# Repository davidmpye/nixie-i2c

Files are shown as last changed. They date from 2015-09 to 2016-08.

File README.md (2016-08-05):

# nixie-i2c

Nixie-I2C is a collection of PCB designs and accompanying library designed to simplify using [Nixie tubes](http://en.wikipedia.org/wiki/Nixie_tube) with Arduino and ESP8266 based boards (and perhaps others in future).

## Design

Driving nixie tubes from microcontrollers can present several issues:
 - Can rely on expensive/obsolute/irreplacable Soviet-era driver ICs (eg K155ID1)
 - Or, if you drive the cathodes directly, requires a large number of pins from the microcontroller (e.g a numeric IN-14 nixie tube has 12 cathodes - 0-9 and left/right decimal places), so it becomes difficult to direct-drive multiple tubes without running out of IO pins
 - If using the 'direct drive' solution above, you need a high-voltage capable transistor per cathode.
 
The main idea of this project is to provide a convenient driver board for a nixie tube, allowing it to be controlled from the microcontroller via I2C.

## Features

The PCB design here (which is tested and works) offers the following features:
 - Bus based (I2C) - put all your tubes in a row on stripboard or similar!
 - Designed for IN-14 nixie tube
 - I2C address (3-bit) settable (solder-pads on underside of board), allowing 9 nixie tubes per I2C bus.
 - Handles all HV switching, allowing a simple library interface to select the digit to be displayed.  Uses cheap SMD NPN transistors (MMBTA42s)
 - Has option for installing a programmable RGB (WS2812B) LED under the base of each tube, allowing bottom-lighting of any colour/brightness, without requiring ongoing control from the microcontroller (eg no PWM timing loops etc)
 - Eagle brd/sch files provided
 - Licenced under the OSHW framework
 
 There is an accompanying library, which supports:
 - Arduino or ESP8266
 - Simple interface to setting a tube's display digit / decimal point status
 - Slot-machine display for cathode protection
 - Direct drive for up to 9 tubes (per I2C bus), no multiplexing/timer loops from the microntroller required
 
##Example

 The library is designed to be simple and easy to use:
 ```
 Nixie_i2c nix0(0x00);
 nix0.slotMachineDisplayNumber(1);  //Tube now displays 1
 delay(1000);
 nix0.slotMachineDisplayNumber(9);  //Tube now displays 9
 ```

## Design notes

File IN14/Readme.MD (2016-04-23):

#IN-14 Nixie Tube I2C PCB design

##Tech Specs:
- Overall dimensions: 24mm x  52.5mm
- Nixie tube centre point: 12mm (ie in the middle of the board in X), 12.3mm in from front edge
- Screw fixing centre 1: 3.25 from edge, 3.25 in from front of board
- Screw fixing centre 2: 3mm from other edge, 19.75mm in from front of board
- Screw hole size: M3
- Pinout(from front to rear):
- - +HV (~170VDC)
- - GND (Common between +HV and VCC)
- - LED_DATA_IN (signal 'in' to WS2812B)
- - LED_DATA_OUT (signal 'out' to next WS2812B in chain)
- - VCC (3.3-5VDC)
- - SCL  (single external 4k7 pull-UP resistor per bus advisable)
- - SDA  (single external 4k7 pull-UP resistor per bus advisable)

##Parts list:
###Top side of board:
- 1x IN-12 nixie tube
- 1x Nixie tube base (3d printable one available as STL file in this folder, with cutout for WS2812B LED)
- 1x WS2812B LED (optional but good!)
- 1x MCP23017 I2C multiplexer IC (SMD)
- 1x 0806 anode resistor 
- 3x 0604 4k7 SMD resistor arrays

##Hints

- Solder the resistor arrays in to place first (flood soldering works best)
- Solder the I2C multiplexer chips and other parts in to place
- Set the I2C address bits on the rear side of the board - bridging the middle and left pad sets the bit to 0, middle and right sets the bit to 1.  Bridging all three pins shorts VCC to GND!
- If mounting PCB to the case, it's best to use nylon bolts - reducing the risk of an electrical fault allowing the anode voltage appearing on the outside of a case!

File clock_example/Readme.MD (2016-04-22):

# Example Arduino/ESP8266 sketch

This is an example sketch for a 6-tube Nixie Clock.

The clock is designed around the IN-14 Nixie-I2C project.

##Parts needed:

-Microcontroller (ESP8266/Arduino etc)
-I2C RTC (Cheap battery-backed DS3232)
-HV PSU (I used one from [PV Electronics](http://www.pvelectronics.co.uk/) but anything suitable for driving the tubes will work.
-6 tubes and i2c boards
-I used a transistor pair to make it possible to PWM dim the HV supply to the tubes, meaning the tube brightness can be dimmed for night-time use.

The clock displays HH MM SS, and the bottom-light colour for the tubes changes throughout the day (from green in the early morning through blues in the afternoon to red by night time)

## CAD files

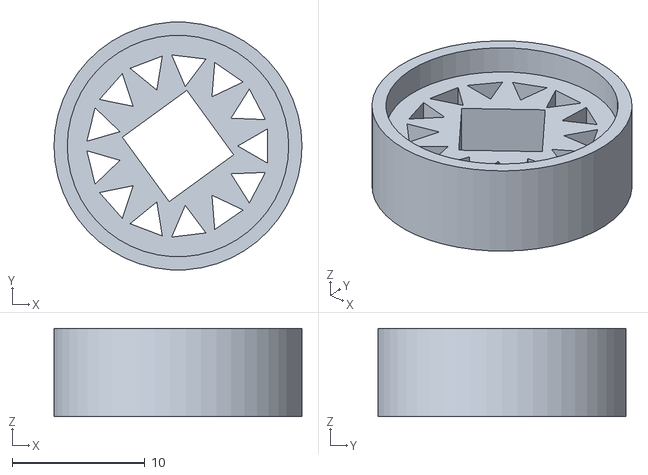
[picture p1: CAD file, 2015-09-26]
IN14/IN14_base.stl
18.7 x 18.6 x 6.65

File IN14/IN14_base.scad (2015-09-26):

outer_dia =  18.67;
lip_height = 2;
lip_width = 1;
total_height = 6.65;

led_length = 6;
led_width = 6;

difference() {

cylinder(r=outer_dia/2, h=total_height, $fn=50);
translate([0, 0, total_height - lip_height]) cylinder(r=(outer_dia/2) - lip_width, h=lip_height + 1, $fn=50);

rotate(360/10,[0,0,1]) translate([-led_length/2,-led_width/2, -1]) cube([led_length, led_width, total_height + 2]);


for (i = [0 : 12]) {

rotate(i * (360/13),[0,0,1]) translate([6,0,-1]) polyhole(total_height + 2, 1.5);
 }
}


module polyhole(h, d) {
    n = max(round(2 * d),3);
    rotate([0,0,180])
        cylinder(h = h, r = (d / 2) / cos (180 / n), $fn = n);
}

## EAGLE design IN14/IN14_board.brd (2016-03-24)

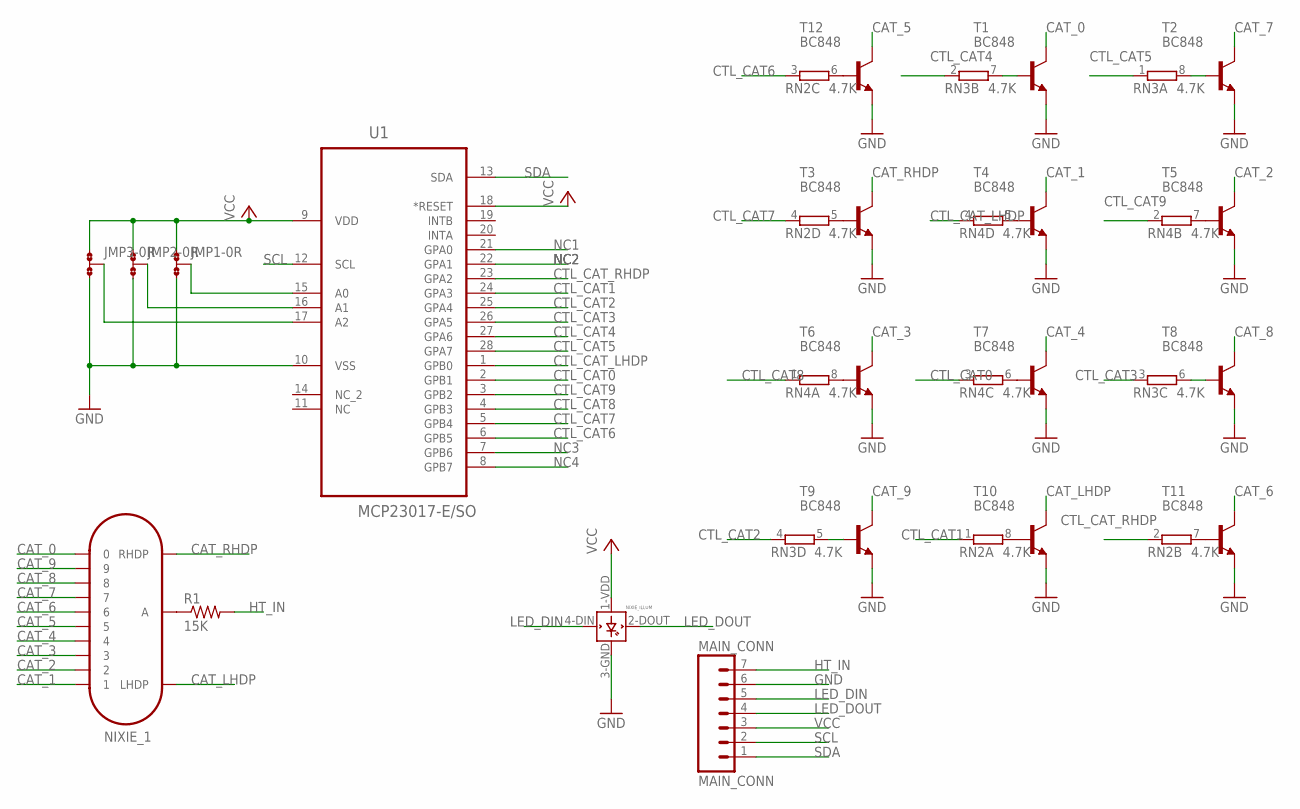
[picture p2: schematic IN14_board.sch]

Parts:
JMP1, JMP2, JMP3: 0R-JUMPA; A0R-JMP
MAIN_CONN: MAIN_CONN; 1X07_LONGPADS
NIXIE_1: IN-14
NIXIE_ILLUM: WS2812B
R1: 15K; 0603-RES
RN2, RN3, RN4: 4.7K; EXB38V
T1, T2, T3, T4, T5, T6, T7, T8, T9, T10, T11, T12: BC848; SOT23
U1: MCP23017-E/SO; SOIC127P1032X265-28N

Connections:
CAT_0: NIXIE_1.0, T1.3 (C)
CAT_1: NIXIE_1.1, T4.3 (C)
CAT_2: NIXIE_1.2, T5.3 (C)
CAT_3: NIXIE_1.3, T6.3 (C)
CAT_4: NIXIE_1.4, T7.3 (C)
CAT_5: NIXIE_1.5, T12.3 (C)
CAT_6: NIXIE_1.6, T11.3 (C)
CAT_7: NIXIE_1.7, T2.3 (C)
CAT_8: NIXIE_1.8, T8.3 (C)
CAT_9: NIXIE_1.9, T9.3 (C)
CAT_LHDP: NIXIE_1.LHDP, T10.3 (C)
CAT_RHDP: NIXIE_1.RHDP, T3.3 (C)
CTL_CAT0: RN4.3 (1), U1.2 (GPB1)
CTL_CAT1: RN2.1, U1.24 (GPA3)
CTL_CAT2: RN3.4 (1), U1.25 (GPA4)
CTL_CAT3: RN3.3 (1), U1.26 (GPA5)
CTL_CAT4: RN3.2 (1), U1.27 (GPA6)
CTL_CAT5: RN3.1, U1.28 (GPA7)
CTL_CAT6: RN2.3 (1), U1.6 (GPB5)
CTL_CAT7: RN2.4 (1), U1.5 (GPB4)
CTL_CAT8: RN4.1, U1.4 (GPB3)
CTL_CAT9: RN4.2 (1), U1.3 (GPB2)
CTL_CAT_LHDP: RN4.4 (1), U1.1 (GPB0)
CTL_CAT_RHDP: RN2.2 (1), U1.23 (GPA2)
GND: JMP1.3, JMP2.3, JMP3.3, MAIN_CONN.6, NIXIE_ILLUM.3-GND (GND), T1.2 (E), T2.2 (E), T3.2 (E), T4.2 (E), T5.2 (E), T6.2 (E), T7.2 (E), T8.2 (E), T9.2 (E), T10.2 (E), T11.2 (E), T12.2 (E), U1.10 (VSS)
HT_IN: MAIN_CONN.7, R1.2
LED_DIN: MAIN_CONN.5, NIXIE_ILLUM.4-DIN (DIN)
LED_DOUT: MAIN_CONN.4, NIXIE_ILLUM.2-DOUT (DOUT)
unnamed: RN3.8 (2), T2.1 (B)
unnamed: JMP1.2, U1.15 (A0)
unnamed: RN3.7 (2), T1.1 (B)
unnamed: NIXIE_1.A, R1.1
unnamed: RN3.6 (2), T8.1 (B)
unnamed: JMP2.2, U1.16 (A1)
unnamed: RN2.5 (2), T3.1 (B)
unnamed: JMP3.2, U1.17 (A2)
unnamed: RN4.5 (2), T4.1 (B)
unnamed: RN4.8 (2), T6.1 (B)
unnamed: RN3.5 (2), T9.1 (B)
unnamed: RN4.7 (2), T5.1 (B)
unnamed: RN4.6 (2), T7.1 (B)
unnamed: RN2.6 (2), T12.1 (B)
unnamed: RN2.7 (2), T11.1 (B)
unnamed: RN2.8 (2), T10.1 (B)
NC1: U1.21 (GPA0)
NC2: U1.22 (GPA1)
NC3: U1.7 (GPB6)
NC4: U1.8 (GPB7)
SCL: MAIN_CONN.2, U1.12 (SCL)
SDA: MAIN_CONN.1, U1.13 (SDA)
VCC: JMP1.1, JMP2.1, JMP3.1, MAIN_CONN.3, NIXIE_ILLUM.1-VDD (VDD), U1.9 (VDD), U1.18 (*RESET)

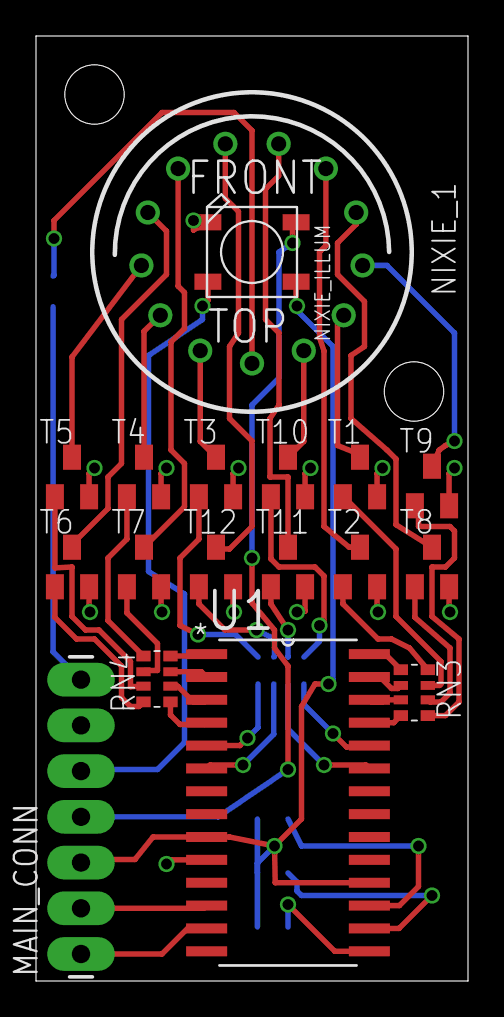
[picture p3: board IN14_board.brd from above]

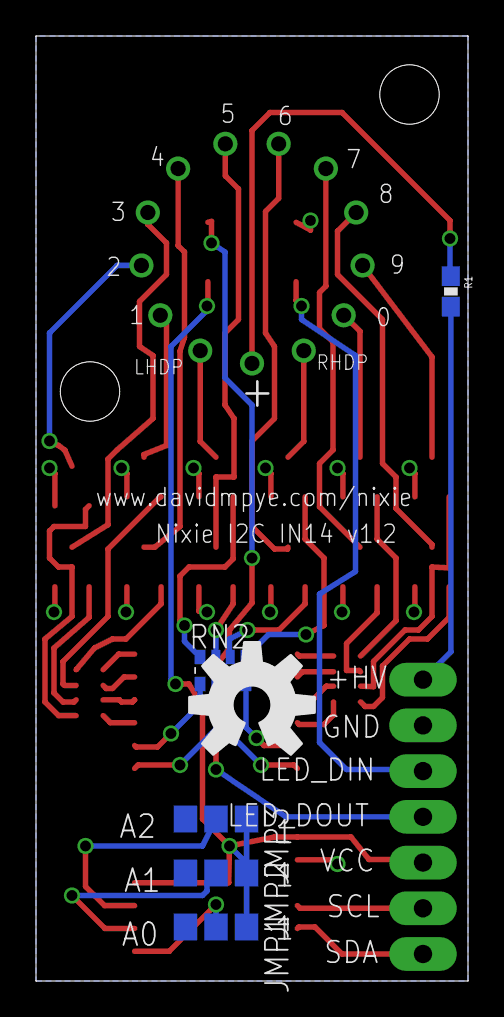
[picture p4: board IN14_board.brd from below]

Board: 2 copper layers, 24.0 x 52.5 mm, 26 parts (6 on the bottom side), 47 nets.

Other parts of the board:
U$1: OSHW-LOGO-L
U$2, U$5: STAND-OFF

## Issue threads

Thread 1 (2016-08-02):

Which transistors are used to drive the cathodes?

msurguy, 2016-08-02:
Hi!

It looks like that the requirements are not listing transistors used in the schematics, could you add them to the readme please?

davidmpye, 2016-08-05:
Oops - they are MMBTA42s.

(e.g. http://uk.farnell.com/webapp/wcs/stores/servlet/ProductDisplay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)

I'll update readme.

Regards

David

msurguy, 2016-08-05:
👍 thanks!

davidmpye, 2016-08-05:
I'm working on a new version of nixie-i2c, which will actually use shift registers, and the boards will be chainable directly (so it'll be nixie-shift, or something ;-)

msurguy, 2016-08-05:
@davidmpye That's great to hear!

I will follow this project but meanwhile I will use Raspberry Pi Zero and Arduinix to control 6 nixie tubes. Really interested in cost efficient addressable single tube solution though, keep up the great work!

msurguy, 2016-08-05:
PS @davidmpye if you haven't already, I highly suggest you put this project on Hackaday.io and let people like me easily follow your progress :)

Closed 2016-08-05.

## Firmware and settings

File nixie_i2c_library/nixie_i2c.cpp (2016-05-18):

/*
  nixie_i2c.cpp - Library for David Pye's nixie i2c boards.
  Created by Dr David Pye - Sept 2015
  Licenced under the GNU GPL v3
*/
#include <nixie_i2c.h>

#define RHDP_PIN 12 
#define LHDP_PIN 3

int Nixie_i2c::_pins[10] = { 8, 6, 4, 5, 7, 2, 13, 9, 11, 10 };

Nixie_i2c::Nixie_i2c(uint8_t i2c_address) {
  _i2c_address = i2c_address;
  
  _currentNumber = -1;
  _lhdpState = _rhdpState = false;
}

void Nixie_i2c::init() {
  _mcp.begin(_i2c_address);
  //Set all pins to o/p
  for (int i=0; i<16; ++i) _mcp.pinMode(i, OUTPUT);
  blank();
}

void Nixie_i2c::displayNumber(int number) {
  _currentNumber = number;
  unblank();
}

void Nixie_i2c::slotMachineDisplayNumber(int newNumber) {

  bool orig_lhdp = _lhdpState;
  bool orig_rhdp = _rhdpState;

  int num = _currentNumber;
  for (int numPasses = 10 + newNumber - num; numPasses >0; --numPasses)  {
 	if (num == 9) num = 0; else num++;

 	//toggle the lhdp/rhdp cathodes as we go round.
 	_lhdpState = !_lhdpState;
    	_rhdpState = !_rhdpState;
	if (numPasses == 1) {
		//Put the decimal point statuses back to the correct ones!
		_lhdpState = orig_lhdp;
		_rhdpState = orig_rhdp;
	}
	displayNumber(num);
	delay(50);
  }
}

void Nixie_i2c::blank() {
  //Set all outputs low
  _mcp.writeGPIOAB(0x0000);
}

void Nixie_i2c::unblank() {
  uint16_t b = 0x0000;
  if (_rhdpState) b |= 1<<RHDP_PIN;
  if (_lhdpState) b |= 1<<LHDP_PIN;
  b |= 1 << _pins[_currentNumber];
  _mcp.writeGPIOAB(b);
}

int Nixie_i2c::currentNumber() {
  return _currentNumber;
}

void Nixie_i2c::setRhdp(bool state) {
  _rhdpState = state;
  _mcp.digitalWrite(RHDP_PIN, _rhdpState ? HIGH: LOW);
}

void Nixie_i2c::setLhdp(bool state) {
  _lhdpState = state;
  _mcp.digitalWrite(LHDP_PIN, _lhdpState ? HIGH: LOW);
}
    

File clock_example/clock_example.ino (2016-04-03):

#include <nixie_i2c.h>
#include <Adafruit_MCP23017.h>
#include <Wire.h>
#include <Adafruit_NeoPixel.h>
#include <DS3232RTC.h>    //http://github.com/JChristensen/DS3232RTC
#include <Time.h>

#define ANODE_PWM_PIN 13

Nixie_i2c nix0(0);
Nixie_i2c nix1(1);

Nixie_i2c nix2(2);
Nixie_i2c nix3(3);
Nixie_i2c nix4(4);
Nixie_i2c nix5(5);

//   #define SET_TIME

//Descriptor for the WS2812 LEDs in the nixie boards
Adafruit_NeoPixel strip = Adafruit_NeoPixel(6, 12, NEO_GRB + NEO_KHZ800);

void setup() {
  Wire.begin(5, 4);

  nix0.init();
  nix1.init();
  nix2.init();
  nix3.init();
  nix4.init();
  nix5.init();

  //set the tubes to full brightness
  pinMode(ANODE_PWM_PIN, OUTPUT);
  analogWrite(ANODE_PWM_PIN, 1024);

  strip.begin();
  strip.setBrightness(100);
  strip.show();

  //Get the current time from the RTC
  setSyncProvider(RTC.get);

#ifdef SET_TIME
  tmElements_t tm;
  tm.Hour = 16;             //set the tm structure to 23h31m30s on 13Feb2009
  tm.Minute = 43;
  tm.Second = 0;
  tm.Day = 03;
  tm.Month = 04;
  tm.Year = 2016 - 1970;    //tmElements_t.Year is the offset from 1970
  RTC.write(tm);
  
#endif

  setColons(true);

}

int lastMinute = -1; //used for RGB colour updates

void loop() {
  time_t currentTime = now();
  int scratch;
  scratch = hour(currentTime) / 10;
  if (nix5.currentNumber() != scratch)  nix5.slotMachineDisplayNumber(scratch);
  scratch = hour(currentTime) % 10;
  if (nix4.currentNumber() != scratch) nix4.slotMachineDisplayNumber(scratch);

  scratch = minute(currentTime) / 10;
  if (nix3.currentNumber() != scratch) nix3.slotMachineDisplayNumber(scratch);
  scratch = minute(currentTime) % 10;
  if (nix2.currentNumber() != scratch) nix2.slotMachineDisplayNumber(scratch);


  scratch = second(currentTime) / 10;
  if (nix1.currentNumber() != scratch) {
    if (nix1.currentNumber() == 5) nix1.slotMachineDisplayNumber(scratch);
    else nix1.displayNumber(scratch);
  }

  scratch = second(currentTime) % 10;
  if (nix0.currentNumber() != scratch) nix0.displayNumber(scratch);


  if (minute(currentTime) != lastMinute) {
    //The color value is set by adding hours(*10) to minutes.
    //Highest val would occur at 23:59.  (230 + 59), so cap it at 255.
    byte magicColorVal = hour(currentTime) * 10 + ( minute(currentTime) / 6) > 255 ? 255 : hour(currentTime) * 10 + (minute(currentTime) / 6) ;

    uint32_t color = Wheel(magicColorVal);

    for (int i = 0; i < 6; ++i) {
      strip.setPixelColor(i, color);
    }
    strip.show();
    lastMinute = minute(currentTime);
  }

  //Handle dimming - we will dim from 11pm to 6am to 50% brightness...
  if (hour(currentTime) > 22 || hour(currentTime) < 6) {
    analogWrite(ANODE_PWM_PIN, 128);
    strip.setBrightness(15);
    strip.show();
  }
  else {
    analogWrite(ANODE_PWM_PIN, 1024);
      strip.setBrightness(100);
      strip.show();
  }
}


void setColons(bool state) {
  nix4.setRhdp(state);
  nix2.setRhdp(state);
}

// Input a value 0 to 255 to get a color value.
// The colours are a transition r - g - b - back to r.
uint32_t Wheel(byte WheelPos) {
  WheelPos = 255 - WheelPos;
  if (WheelPos < 85) {
    return strip.Color(255 - WheelPos * 3, 0, WheelPos * 3);
  }
  if (WheelPos < 170) {
    WheelPos -= 85;
    return strip.Color(0, WheelPos * 3, 255 - WheelPos * 3);
  }
  WheelPos -= 170;
  return strip.Color(WheelPos * 3, 255 - WheelPos * 3, 0);
}

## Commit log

2015-09-25 Initial import of IN14 boards
    [IN14_board.brd, IN14_board.sch]
2015-09-25 Gerbers added
    [IN14_board.GBL, IN14_board.GBO, IN14_board.GBS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]
2015-09-26 IN14 3d printed bases added
    [IN14_base.scad, IN14_base.stl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]
2015-09-26 move dirs
    [IN14_base.scad, IN14_base.stl]
2015-09-26 First draft of arduino library
2015-09-28 More sensible slot machine change code
2016-03-24 Added files via upload
    New 'thinner' board - now revision 1.2. Pincompatible with previous bus-driven designs, but library code will need to be adjusted as the pins are mapped differently for economy of space!
    [IN14_board.brd, IN14_board.sch]
2016-03-24 Added files via upload
    Move transistor down slightly to improve mounting hole clearance
    [IN14_board.brd]
2016-03-24 Added files via upload
    Moved a transistor for hole clearance improvement
2016-03-25 Moved files in together!
    [IN14_board.brd]
2016-03-25 New gerbers for 1.2v board
    [IN14_board.GBL, IN14_board.GBO, IN14_board.GBS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]
2016-04-02 Update for new PCB layout
2016-04-17 Oops - fixed RHDP/LHDP mixup
    [nixie_i2c.cpp]
2016-05-16 Update to add currentNumber functionality
2016-05-18 Fix bug where tube isn't initialised properly
    [nixie_i2c.cpp]

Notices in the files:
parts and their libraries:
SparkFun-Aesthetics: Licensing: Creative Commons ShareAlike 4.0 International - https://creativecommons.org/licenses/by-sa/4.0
